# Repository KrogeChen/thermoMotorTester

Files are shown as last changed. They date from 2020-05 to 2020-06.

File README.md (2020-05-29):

# thermoMotorTester

热马达综合测试仪

## 功能介绍

- 测试热马达的行程、温度、负载力、功率、电压、电流
- 系统电压DC12-24V
- 测试电压AC12、AC24V、AC36V、AC110、AC220V
- 需要配置PC端软件，记录参数的曲线
- 能够长期运行对产品进行老化

## 系统组成 

- 主控板、继电器输出板、测力仪、电参数测量仪、温控仪、变压器、PC软件

## 器件选型

* [MCU:STM32F103RCT6](https://github.com/KrogeChen/thermoMotorTester/tree/master/document/STM32F103) 
* [继电器:HF115-005-2ZS](https://github.com/KrogeChen/thermoMotorTester/tree/master/document/HF115F_005-2ZS4AF) 
* [电参:PM9808](https://github.com/KrogeChen/thermoMotorTester/tree/master/document/PM9808) 
* [温控仪:LU-926M](https://github.com/KrogeChen/thermoMotorTester/tree/master/document/LU_926M) 

## 设计说明

- 设备电压:AC220V 
- 主板实现电压的转换、测量数据的采集
- 测试电压输出采用继电器触点互锁的方式、任何时候只允许输出一组电压。
- 设计7个输入点、7个输出点
- 5组UART通讯(2组RS323、1组RS485、1组TTL、1组BGH)
- 主要协议modbus RTU 主机，bough

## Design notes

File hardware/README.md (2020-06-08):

# 硬件目录
硬件Kicad库(https://github.com/KrogeChen/kicadLib)

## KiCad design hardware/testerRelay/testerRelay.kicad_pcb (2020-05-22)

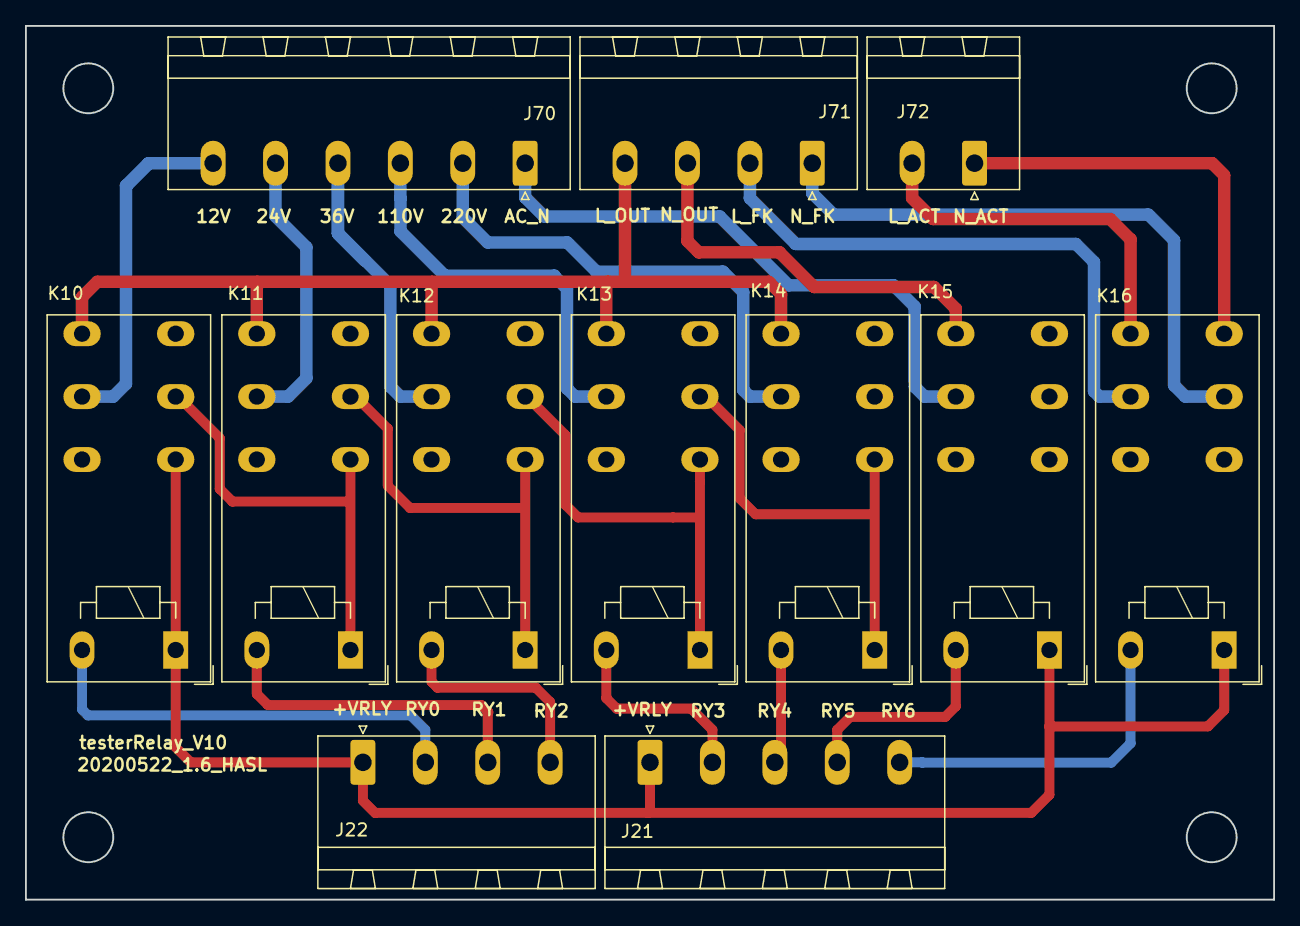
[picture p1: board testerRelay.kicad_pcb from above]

Board: 2 copper layers, 100.0 x 70.0 mm, 12 parts (0 on the bottom side), 24 nets.

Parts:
J21: relay; PhoenixContact_MSTBA_2,5_5-G_1x05_P5.00mm_Horizontal
J22: relay; PhoenixContact_MSTBA_2,5_4-G_1x04_P5.00mm_Horizontal
J70: transformer; PhoenixContact_MSTBA_2,5_6-G_1x06_P5.00mm_Horizontal
J71: PM9808_L; PhoenixContact_MSTBA_2,5_4-G_1x04_P5.00mm_Horizontal
J72: actuator; PhoenixContact_MSTBA_2,5_2-G_1x02_P5.00mm_Horizontal
K10, K11, K12, K13, K14, K15, K16: HF115-005-2ZS4; Relay_DPDT_Schrack-RT2-FormC_RM5mm

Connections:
/+VRLY: J21.1, J22.1, K10.12, K10.A1, K15.A1, K16.A1
/AC12V: J70.6, K10.21
/AC24V: J70.5, K11.21
/AC36V: J70.4, K12.21
/AC110V: J70.3, K13.21
/AC220V: J70.2, K14.21
/AC_N: J70.1, K15.21
/C_CK0: J22.2, K10.A2
/C_CK1: J22.3, K11.A2
/C_CK2: J22.4, K12.A2
/C_CK3: J21.2, K13.A2
/C_CK4: J21.3, K14.A2
/C_CK5: J21.4, K15.A2
/C_CK6: J21.5, K16.A2
/K11CV: K10.11, K11.12, K11.A1
/K12CV: K11.11, K12.12, K12.A1
/K13CV: K12.11, K13.12, K13.A1
/K14CV: K13.11, K14.12, K14.A1
/L_ACT: J72.2, K16.24
/L_FK: J71.2, K16.21
/L_OUT: J71.4, K10.24, K11.24, K12.24, K13.24, K14.24
/N_ACT: J72.1, K16.14
/N_FK: J71.1, K16.11
/N_OUT: J71.3, K15.24

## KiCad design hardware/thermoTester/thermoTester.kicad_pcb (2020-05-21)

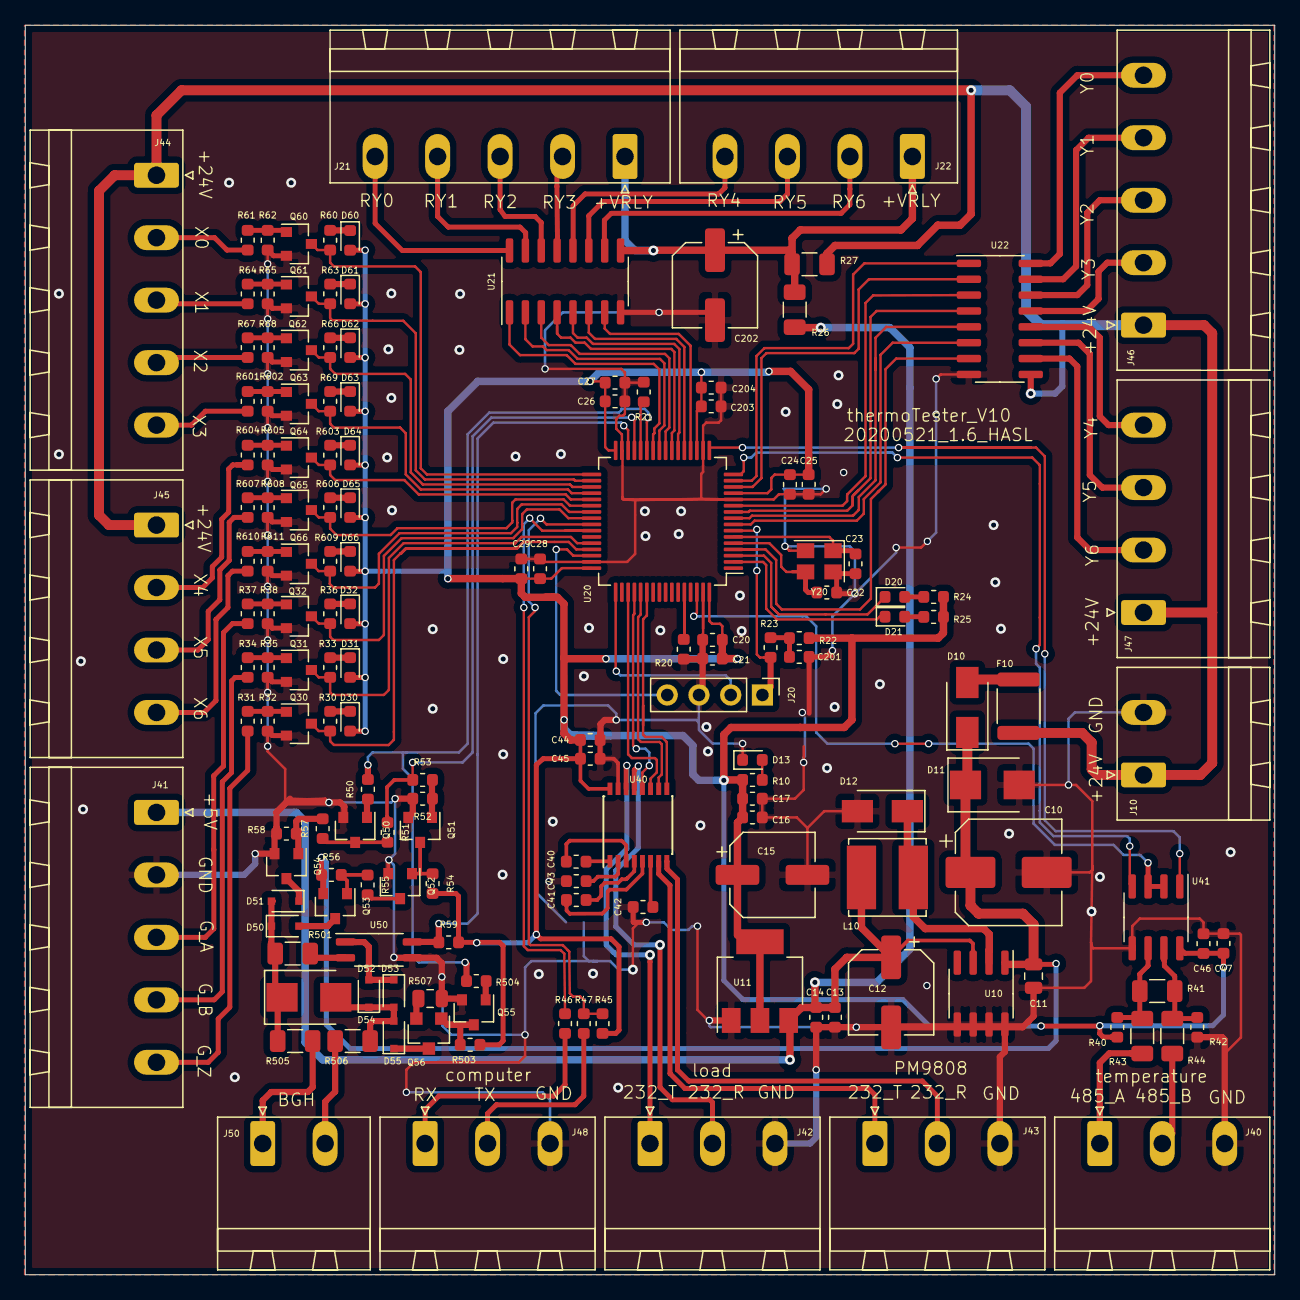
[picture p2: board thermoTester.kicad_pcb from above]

Board: 2 copper layers, 100.0 x 100.0 mm, 157 parts (0 on the bottom side), 136 nets.

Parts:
C10: 47uF; CP_Elec_8x6.5
C11: 1uF; C_0805_2012Metric
C12, C15, C202: 220uF; CP_Elec_6.3x5.4
C13, C16, C20, C25, C26, C29, C44, C47, C204: 1uF; C_0603_1608Metric
C14, C17, C21, C24, C27, C28, C40, C41, C42, C43, C45, C46, C201, C203: 100nF; C_0603_1608Metric
C22, C23: 20pF; C_0603_1608Metric
D10, D12: SS14; D_SMA
D11: SMBJ28A; D_SMB
D13, D20, D21: Red; LED_0603_1608Metric
D30, D31, D32, D60, D61, D62, D63, D64, D65, D66: Red; D_0603_1608Metric
D50, D51, D52, D53, D55: 1N4148; D_SOD-323F
D54: SMBJ28CA; D_SMB
F10: 100mA; Fuse_1812_4532Metric
J10: Power; PhoenixContact_MSTBA_2,5_2-G_1x02_P5.00mm_Horizontal
J20: PRG; PinHeader_1x04_P2.54mm_Vertical
J21: relay; PhoenixContact_MSTBA_2,5_5-G_1x05_P5.00mm_Horizontal
J22: relay; PhoenixContact_MSTBA_2,5_4-G_1x04_P5.00mm_Horizontal
J40: temperature; PhoenixContact_MSTBA_2,5_3-G_1x03_P5.00mm_Horizontal
J41: grating; PhoenixContact_MSTBA_2,5_5-G_1x05_P5.00mm_Horizontal
J42: load; PhoenixContact_MSTBA_2,5_3-G_1x03_P5.00mm_Horizontal
J43: PM9808_TR; PhoenixContact_MSTBA_2,5_3-G_1x03_P5.00mm_Horizontal
J44: key_in; PhoenixContact_MSTBA_2,5_5-G_1x05_P5.00mm_Horizontal
J45: key_in; PhoenixContact_MSTBA_2,5_4-G_1x04_P5.00mm_Horizontal
J46: lamp; PhoenixContact_MSTBA_2,5_5-G_1x05_P5.00mm_Horizontal
J47: lamp; PhoenixContact_MSTBA_2,5_4-G_1x04_P5.00mm_Horizontal
J48: CPTTL; PhoenixContact_MSTBA_2,5_3-G_1x03_P5.00mm_Horizontal
J50: bough; PhoenixContact_MSTBA_2,5_2-G_1x02_P5.00mm_Horizontal
L10: 68uH; L_Bourns_SRN6045TA
Q30, Q31, Q32, Q50, Q51, Q52, Q54, Q55, Q60, Q61, Q62, Q63, Q64, Q65, Q66: BC817; SOT-23
Q53: BC807; SOT-23
Q56: AO3400; SOT-23_big
R10, R20, R21, R24, R25, R51, R57: 2.7k; R_0603_1608Metric
R22, R52: 47k; R_0603_1608Metric
R23: 470; R_0603_1608Metric
R26: 0; R_1206_3216Metric
R27: NP(0); R_1206_3216Metric
R30, R31, R32, R33, R34, R35, R36, R37, R38, R40, R42, R45, R50, R54, R55, R56, R60, R61, R62, R63, R64, R65, R66, R67, R68, R69, R503, R504, R601, R602, R603, R604, R605, R606, R607, R608, R609, R610, R611: 10k; R_0603_1608Metric
R41: NP_120; R_1206_3216Metric
R43, R44: 20; R_1206_3216Metric
R46, R47: 100; R_0603_1608Metric
R53, R58, R59: 5.1k; R_0603_1608Metric
R501: 5.1k; R_1206_3216Metric
R505, R506: 20R; R_1206_3216Metric
R507: 1R; R_0805_2012Metric
U10: XL1509; SOIC-8_3.9x4.9mm_P1.27mm
U11: LM1117-3.3; SOT-223
U20: M_STM32F103RCT6; LQFP-64_10x10mm_P0.5mm
U21, U22: ULN2003; SOIC-16_3.9x9.9mm_P1.27mm
U40: SP3232; SSOP-16_4.4x5.2mm_P0.65mm
U41: SP3485CN; SOIC-8_3.9x4.9mm_P1.27mm
U50: EL3H4B; SSOP-4_2.7x5.05mm_P1.27mm
Y20: 12M; Crystal_SMD_3225-4Pin_3.2x2.5mm

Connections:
+5VD: C12.1, C13.1, C14.1, J41.1, L10.2, R26.1, U10.3, U11.3
/BGH1: J50.1, R505.1
/BGH2: J50.2, R506.1
/CP_RX: J48.1, R46.2
/CP_TX: J48.2, R47.2
/C_CK0: J21.5, U21.16
/C_CK1: J21.4, U21.15
/C_CK2: J21.3, U21.14
/C_CK3: J21.2, U21.13
/C_CK4: J22.4, U21.12
/C_CK5: J22.3, U21.11
/C_CK6: J22.2, U21.10
/LED0: D20.1, U20.3
/LED1: D21.1, U20.2
/MKSV1: Q63.3, R69.2, U20.36
/MKSV2: Q64.3, R603.2, U20.37
/MKSV3: Q65.3, R606.2, U20.38
/MKSV4: Q66.3, R609.2, U20.39
/MLs1: U20.11, U22.3
/MLs2: U20.10, U22.4
/MLs3: U20.9, U22.5
/MLs4: U20.8, U22.6
/MLs5: U20.4, U22.7
/MRX1: R46.1, U20.42
/MRX2: U20.17, U41.1
/MRX3: R59.1, U20.30, U50.4
/MRX4: U20.52, U40.12
/MRX5: U20.54, U40.9
/MSTP: Q62.3, R66.2, U20.35
/MSTR: Q61.3, R63.2, U20.34
/MTA: Q32.3, R36.2, U20.40
/MTB: Q31.3, R33.2, U20.44
/MTX1: R45.1, R47.1, U20.41
/MTX2: U20.16, U41.4
/MTX3: R51.1, R53.1, U20.29
/MTX4: U20.51, U40.11
/MTX5: U20.53, U40.10
/MTZ: Q30.3, R30.2, U20.45
/MVGS: Q60.3, R60.2, U20.33
/M_CK0: U20.26, U21.1
/M_CK1: U20.25, U21.2
/M_CK2: U20.24, U21.3
/M_CK3: U20.23, U21.4
/M_CK4: U20.22, U21.5
/M_CK5: U20.21, U21.6
/M_CK6: U20.20, U21.7
/Mrun: U20.15, U22.1
/Mtest: U20.14, U22.2
/NRST: J20.1, R23.2, U20.7
/OVLD: Q56.2, R507.2
/RS1_A: J40.1, R43.1
/RS1_B: J40.2, R44.1
/RS2_R: J42.2, U40.13
/RS2_T: J42.1, U40.14
/RS3_R: J43.2, U40.8
/RS3_T: J43.1, U40.7
/SWCLK: J20.2, U20.49
/SWDIO: J20.4, U20.46
/TRS: R50.2, R504.1, U20.27
/TR_S1: U20.62, U41.2, U41.3
/TTL_A: J41.3, R37.1
/TTL_B: J41.4, R34.1
/TTL_Z: J41.5, R31.1
/VIN: F10.1, J10.1, J44.1, J45.1, J46.1, J47.1, R27.1, U22.9
/VRLY: C202.1, J21.1, J22.1, R26.2, R27.2, U21.9
/key_rsv1: J44.5, R601.1
/key_rsv2: J45.2, R604.1
/key_rsv3: J45.3, R607.1
/key_rsv4: J45.4, R610.1
/lamp_rsv1: J46.3, U22.14
/lamp_rsv2: J46.2, U22.13
/lamp_rsv3: J47.4, U22.12
/lamp_rsv4: J47.3, U22.11
/lamp_rsv5: J47.2, U22.10
/run: J46.5, U22.16
/start: J44.3, R64.1
/stop: J44.4, R67.1
/test: J46.4, U22.15
/voltage_s: J44.2, R61.1
GND: C10.2, C11.2, C12.2, C13.2, C14.2, C15.2, C16.2, C17.2, C20.1, C21.1, C22.2, C23.2, C24.1, C25.1, C26.2, C27.1, C28.1, C29.2, C42.2, C43.2, C44.2, C45.1, C46.2, C47.2, C201.2, C202.2, C203.2, C204.2, D11.2, D12.2, D13.1, J10.2, J20.3, J40.3, J41.2, J42.3, J43.3, J48.3, Q30.2, Q31.2, Q32.2, Q50.2, Q51.2, Q52.2, Q54.2, Q55.2, Q60.2, Q61.2, Q62.2, Q63.2, Q64.2, Q65.2, Q66.2, R20.2, R21.1, R32.2, R35.2, R38.2, R42.1, R52.2, R58.2, R62.2, R65.2, R68.2, R507.1, R602.2, R605.2, R608.2, R611.2, U10.5, U10.6, U10.7, U10.8, U11.1, U20.12, U20.18, U20.31, U20.47, U20.63, U21.8, U22.8, U40.15, U41.5, U50.3, Y20.2, Y20.4
unnamed: C22.1, U20.5, Y20.3
unnamed: C23.1, U20.6, Y20.1
unnamed: C40.1, U40.1
unnamed: C40.2, U40.3
unnamed: C41.1, U40.4
unnamed: C41.2, U40.5
unnamed: C42.1, U40.6
unnamed: C43.1, U40.2
unnamed: C201.1, R22.2, R23.1
unnamed: D10.2, F10.2
unnamed: D12.1, L10.1, U10.2
unnamed: D13.2, R10.1
unnamed: D20.2, R24.2
unnamed: D21.2, R25.2
unnamed: D30.1, R30.1
unnamed: D31.1, R33.1
unnamed: D32.1, R36.1
unnamed: D50.1, D51.2, D54.1, R501.2, R505.2
unnamed: D50.2, Q53.3
unnamed: D51.1, Q54.3
unnamed: D52.1, D53.2, D54.2, D55.2, R506.2
unnamed: D52.2, D53.1, U50.1
unnamed: D55.1, Q56.3
unnamed: D60.1, R60.1
unnamed: D61.1, R63.1
unnamed: D62.1, R66.1
unnamed: D63.1, R69.1
unnamed: D64.1, R603.1
unnamed: D65.1, R606.1
unnamed: D66.1, R609.1
unnamed: Q30.1, R31.2, R32.1
unnamed: Q31.1, R34.2, R35.1
unnamed: Q32.1, R37.2, R38.1
unnamed: Q50.1, R50.1
unnamed: Q50.3, R51.2, R57.1
unnamed: Q51.1, R52.1, R53.2
unnamed: Q51.3, Q52.1, R54.1
unnamed: Q52.3, R55.2
unnamed: Q53.1, R55.1, R56.2
unnamed: Q54.1, R57.2, R58.1
unnamed: Q55.1, R504.2
unnamed: Q55.3, Q56.1, R503.2
unnamed: Q60.1, R61.2, R62.1
unnamed: Q61.1, R64.2, R65.1
unnamed: Q62.1, R67.2, R68.1
unnamed: Q63.1, R601.2, R602.1
unnamed: Q64.1, R604.2, R605.1
unnamed: Q65.1, R607.2, R608.1
unnamed: Q66.1, R610.2, R611.1
unnamed: R20.1, U20.60
unnamed: R21.2, U20.28
unnamed: R40.1, R41.2, R43.2, U41.6
unnamed: R41.1, R42.2, R44.2, U41.7
unnamed: R501.1, U50.2
VCC: C15.1, C16.1, C17.1, C20.2, C21.2, C24.2, C25.2, C26.1, C27.2, C28.2, C29.1, C44.1, C45.2, C46.1, C47.1, C203.1, C204.1, D30.2, D31.2, D32.2, D60.2, D61.2, D62.2, D63.2, D64.2, D65.2, D66.2, R10.2, R22.1, R24.1, R25.1, R40.2, R45.2, R54.2, R59.2, R503.1, U11.2, U11.4, U20.13, U20.19, U20.32, U20.48, U20.64, U40.16, U41.8
VDD: C10.1, C11.1, D10.1, D11.1, Q53.2, R56.1, U10.1

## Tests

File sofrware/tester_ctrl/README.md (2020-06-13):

## 主控板软件
MCU: STM32F103RCT6
edit: vscode

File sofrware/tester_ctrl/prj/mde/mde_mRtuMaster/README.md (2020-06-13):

## modbus rtu protocol 
- master program

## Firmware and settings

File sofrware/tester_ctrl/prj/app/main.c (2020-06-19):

//+++++++++++++++++++++++++++++++++++++++++++++++++++++++++++++++++++++++++++++
#include ".\app_cfg.h"
//+++++++++++++++++++++++++++++++++++++++++++++++++++++++++++++++++++++++++++++
int main (void)
{
    pbc_createTask_one(app_general_task,0);
    pbc_createTask_one(app_modbus_task,0);
//-----------------------------------------------------------------------------
    pbc_sysTickTaskProcess();
}
//+++++++++++++++++++++++++++++++++++++++++++++++++++++++++++++++++++++++++++++

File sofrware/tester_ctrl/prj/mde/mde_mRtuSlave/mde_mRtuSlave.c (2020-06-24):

//+++++++++++++++++++++++++++++++++++++++++++++++++++++++++++++++++++++++++++++
//+++++++++++++++++++++++++++++++++++++++++++++++++++++++++++++++++++++++++++++
#include ".\mde_mRtuSlave.h"
#include "..\..\pbc\pbc_dataConvert\pbc_dataConvert.h"
#include "..\..\pbc\pbc_crc16\pbc_crc16.h"
#include "..\..\pbc\pbc_sysTick\pbc_sysTick.h"
#include ".\depend\bsp_mRtuSlave.h"
//-----------------------------------------------------------------------------
//+++++++++++++++++++++++++++++++++++++++++++++++++++++++++++++++++++++++++++++
//modbus 从机模块,负责报文的接收和应答控制
//支持命令: 0x03 0x06 0x10 0x17
//支持多个实例
//+++++++++++++++++++++++++++++++++++++++++++++++++++++++++++++++++++++++++++++
typedef enum
{
    mRunS_idle             = 0x00,
    mRunS_receive_wait,
    mRunS_receive_data,
    mRunS_receive_end,
    mRunS_transmit_str,
    mRunS_transmit_35T,
    mRunS_transmit_data,
    mRunS_transmit_stop,
    mRunS_transmit_end,
}modbus_runStatus_def;
//+++++++++++++++++++++++++++++++++++++++++++++++++++++++++++++++++++++++++++++
//modbus操作结构体
//-----------------------------------------------------------------------------
typedef struct
{
    mRtu_parameter_def  mRtu_parameter;
    mRtu_status_def     mRtu_status;
    modbus_runStatus_def  moo_runStutus;
    sdt_int8u  receive_buff[256];
    sdt_int8u  rev_index;
    sdt_int8u  transmit_buff[256];
    sdt_int16u transmit_regAddrStr;
    sdt_int8u  transmit_length;
    sdt_int8u  transmit_index;
    timerClock_def timer_revTimeOut;

    sdt_int16u  readReg_addr;
    sdt_int8u   readReg_length;
    sdt_int16u  writeReg_addr;
    sdt_int8u   writeReg_length;

    void (*phy_into_receive)(void);
    sdt_bool (*pull_receive_byte)(sdt_int8u* out_rByte);
    sdt_bool (*pull_busFree)(sdt_int8u t_char_dis);
    void (*restart_busFree_timer)(void);

    void (*phy_into_transmit_status)(void);
    sdt_bool (*push_transmit_byte)(sdt_int8u in_tByte);
    sdt_bool (*pull_transmit_complete)(void);
}modbus_oper_def;
//+++++++++++++++++++++++++++++++++++++++++++++++++++++++++++++++++++++++++++++

//+++++++++++++++++++++++++++++++++++++++++++++++++++++++++++++++++++++++++++++
//name:potocol command
//out: true -- 协议解释完毕，false -- 协议解释失败
//-----------------------------------------------------------------------------
static sdt_bool modbus_receive_protocol(modbus_oper_def* mix_oper)
{
    sdt_int8u rd_length;

    rd_length = mix_oper->rev_index;
    if(rd_length < 6)
    {
        return(sdt_false);
    }
    else
    { 
        if((mix_oper->mRtu_parameter.mRtu_address == mix_oper->receive_buff[0]) || (0xFE == mix_oper->receive_buff[0]) || (0xFA == mix_oper->receive_buff[0]))  //address
        {
            sdt_int8u crc_value[2];
            Crc16CalculateOfByte(&mix_oper->receive_buff[0],(rd_length-2),&crc_value[0]);
            if((crc_value[1] == mix_oper->receive_buff[rd_length-2]) && (crc_value[0] == mix_oper->receive_buff[rd_length-1]))//crc
            {
                
                if(0x03 == mix_oper->receive_buff[1])
                {
                    mix_oper->readReg_addr = pbc_arrayToInt16u_bigEndian(&mix_oper->receive_buff[2]);
                    mix_oper->readReg_length = pbc_arrayToInt16u_bigEndian(&mix_oper->receive_buff[4]);

                    mix_oper->transmit_buff[0] = mix_oper->mRtu_parameter.mRtu_address;
                    mix_oper->transmit_buff[1] = 0x03;
                    mix_oper->transmit_buff[2] = mix_oper->readReg_length * 2;//byte count
                    mix_oper->transmit_length = 3;

                    mix_oper->mRtu_status = mRtuS_read;
                }
                else if(0x06 == mix_oper->receive_buff[1])
                {
                    mix_oper->writeReg_addr = pbc_arrayToInt16u_bigEndian(&mix_oper->receive_buff[2]);
                    mix_oper->writeReg_length = 1;
                    
                    mix_oper->transmit_buff[0] = mix_oper->mRtu_parameter.mRtu_address;
                    mix_oper->transmit_buff[1] = 0x06;
                    mix_oper->transmit_buff[2] = mix_oper->receive_buff[2];
                    mix_oper->transmit_buff[3] = mix_oper->receive_buff[3];
                    mix_oper->transmit_buff[4] = mix_oper->receive_buff[4];
                    mix_oper->transmit_buff[5] = mix_oper->receive_buff[5];
                    mix_oper->transmit_length = 6;

                    mix_oper->mRtu_status = mRtuS_write;
                }
                else if(0x10 == mix_oper->receive_buff[1])
                {
                    mix_oper->writeReg_addr = pbc_arrayToInt16u_bigEndian(&mix_oper->receive_buff[2]);
                    mix_oper->writeReg_length = pbc_arrayToInt16u_bigEndian(&mix_oper->receive_buff[4]);
                    
                    mix_oper->transmit_buff[0] = mix_oper->mRtu_parameter.mRtu_address;
                    mix_oper->transmit_buff[1] = 0x10;
                    mix_oper->transmit_buff[2] = mix_oper->receive_buff[2];
                    mix_oper->transmit_buff[3] = mix_oper->receive_buff[3];
                    mix_oper->transmit_buff[4] = mix_oper->receive_buff[4];
                    mix_oper->transmit_buff[5] = mix_oper->receive_buff[5];
                    mix_oper->transmit_length = 6;

                    mix_oper->mRtu_status = mRtuS_write;
                }
                else if(0x17 == mix_oper->receive_buff[1])
                {
                    mix_oper->readReg_addr = pbc_arrayToInt16u_bigEndian(&mix_oper->receive_buff[2]);
                    mix_oper->readReg_length = pbc_arrayToInt16u_bigEndian(&mix_oper->receive_buff[4]);
                    mix_oper->writeReg_addr = pbc_arrayToInt16u_bigEndian(&mix_oper->receive_buff[6]);
                    mix_oper->writeReg_length = pbc_arrayToInt16u_bigEndian(&mix_oper->receive_buff[8]);
                    
                    mix_oper->transmit_buff[0] = mix_oper->mRtu_parameter.mRtu_address;
                    mix_oper->transmit_buff[1] = 0x17;
                    mix_oper->transmit_buff[2] = mix_oper->readReg_length * 2;
                    mix_oper->transmit_length = 3;

                    mix_oper->mRtu_status = mRtuS_rwBoth;
                }
                else
                {
                    return(sdt_false);
                }
                return(sdt_true);
            }
        }
    }
    return(sdt_false);
}
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

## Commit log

2020-05-13 thermoMotor tester work is start
    [thermoTester.kicad_pcb, thermoTester.sch]
2020-05-21 hardware design is complete
    [thermoTester.kicad_pcb, thermoTester.sch]
2020-05-21 relay out pcb is design
    [testerRelay.kicad_pcb, testerRelay.sch]
2020-05-22 adjustment line direction
    [testerRelay.kicad_pcb]
2020-05-28 创建目录的readme文件
2020-05-28 产品硬件目录增加readme
2020-05-29 增加电参测量仪的通信资料
2020-05-29 上传继电器datasheets
2020-05-29 add temperature control
2020-05-31 Update README.md
    add kicad lib url
2020-06-08 增加触摸屏的开发资料
2020-06-22 modbus可以较为稳定运行的版本
2020-06-24 修改模块，采用结构体数组的方式存储实例
2020-06-28 完善光栅模块，加入数字输入、输出模块
    [thermoTester.sch]
2020-06-29 增加触摸屏的工程文件
